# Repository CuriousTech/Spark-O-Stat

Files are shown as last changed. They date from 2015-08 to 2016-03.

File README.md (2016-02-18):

## Spark-O-Stat
SparkCore based WiFi thermostat project

Note: As of 2/18/2016 the SparkCore code is depreciated.  The Photon is now in use, and all changes will be made there.  A new large font has been added since there's more room, and data is published instead of read.  The HTML page and .js scripts will not work with the old code.

This is my first GitHib project, and the idea is simple.  It's opensource and flexible with a color LCD touchscreen, rotary encoder and speaker to allow room for creative software.  The initial concept will be to control for efficiency by scaling the indoor temperature to outdoor instead of drastic bumps using schedules, and adjustments using predictive code based on experiment and observation.  But all that can be removed and replaced with schedules if desired.

UI

A periodic screenshot of data collection: This is sometime in the summer.  The orange temp is in another room.  Unfortunately the thermostat gets the most sun in the house, so it's the most erratic.   I've noticed the AC doesn't run at the low and high points of the day as it used to.  That was unexpected.  And the electric bill was down about 30% most of this year.  

graph

This is the older desktop control running on PngMagic  

control

More info at http://www.curioustech.net/curiousprojects.html

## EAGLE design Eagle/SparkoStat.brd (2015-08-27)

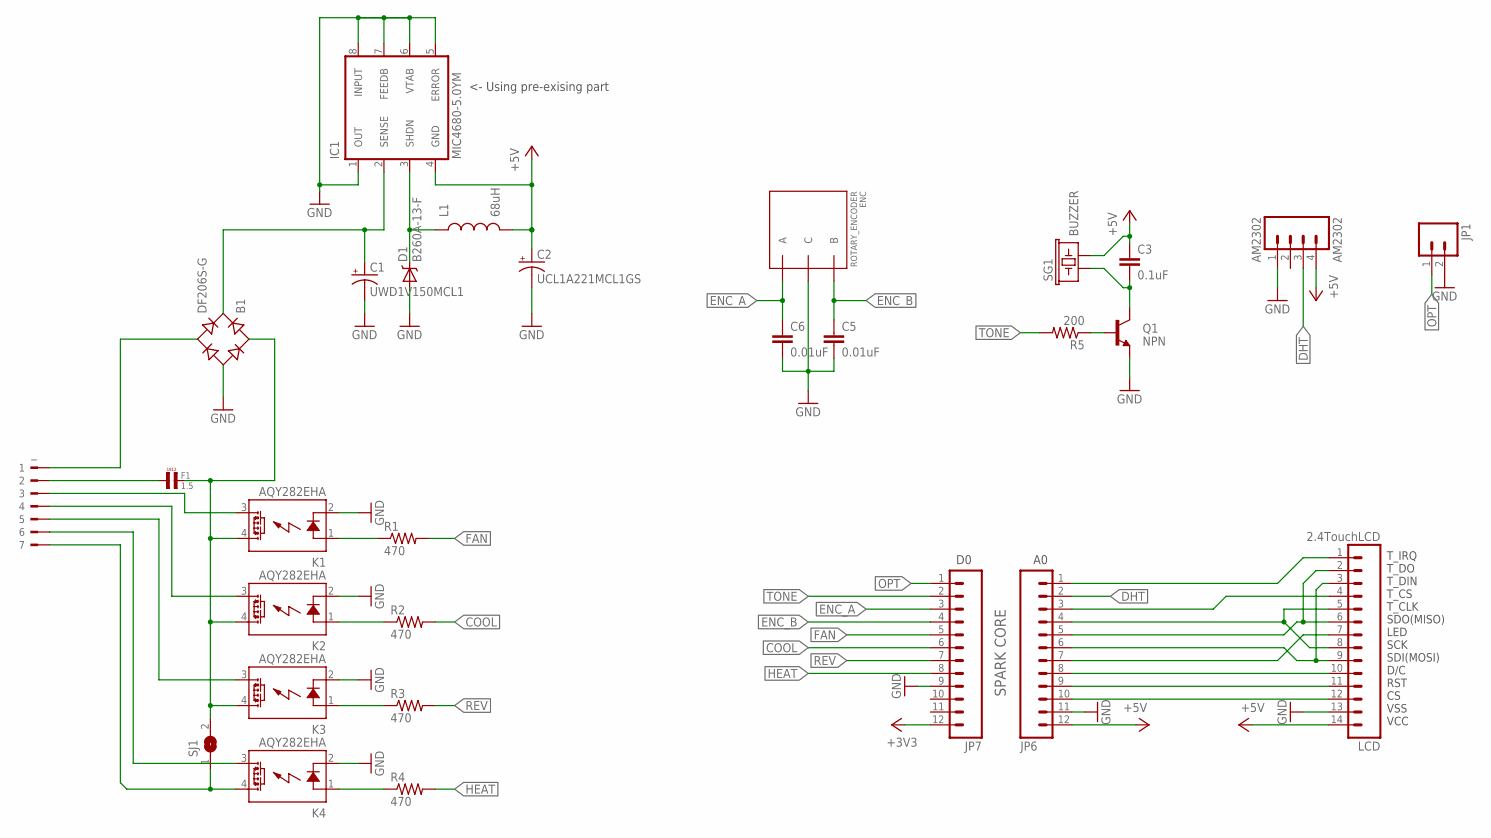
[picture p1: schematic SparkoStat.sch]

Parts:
AM2302: AM2302; 1X04
B1: DF206S-G; DFS
C1: UWD1V150MCL1; PANASONIC_C
C2: UCL1A221MCL1GS; PANASONIC_D
C3: 0.1uF; 0805
C5, C6: 0.01uF; 0805
D1: B260A-13-F; SMA-DIODE
ENC: ROTARY_ENCODER; ROTORY_ENC
F1: 1.5; L4,8
IC1: MIC4680-5.0YM; SO-08
JP1: M02PTH; 1X02
JP6, JP7: M12LOCK; 1X12_LOCK
K1, K2, K3, K4: AQY282EHA; SOP04
L1: 68uH; DR1030
LCD: 2.4TouchLCD; 1X14_LOCK
Q1: NPN; SOT23
R1, R2, R3, R4: 470; 0805
R5: 200; 0805
SG1: BUZZER; BUZZER-12MM-NS
SJ1: SJ
_: 180-7

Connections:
+3V3: JP7.12
+5V: AM2302.4, C2.+, C3.1, IC1.4 (GND), JP6.12, L1.2, LCD.14, SG1.- (2)
COOL: JP7.6, R2.2
DHT: AM2302.3, JP6.2
ENC_A: C6.1, ENC.A, JP7.3
ENC_B: C5.1, ENC.B, JP7.4
FAN: JP7.5, R1.2
GND: AM2302.1, B1.-, C1.-, C2.-, C5.2, C6.2, D1.A, ENC.C, IC1.1 (OUT), IC1.5 (ERROR), IC1.6 (VTAB), IC1.7 (FEEDB), IC1.8 (INPUT), JP1.2, JP6.11, JP7.9, K1.2 (K), K2.2 (K), K3.2 (K), K4.2 (K), LCD.13, Q1.2 (E)
HEAT: JP7.8, R4.2
unnamed: JP6.1, LCD.1
unnamed: D1.C, IC1.3 (SHDN), L1.1
unnamed: K4.3 (DS2), _.6
unnamed: K1.1 (A), R1.1
unnamed: K2.1 (A), R2.1
unnamed: B1.AC1, F1.P$2 (2), K1.4 (DS1), K2.4 (DS1), K3.4 (DS1), SJ1.2
unnamed: K3.1 (A), R3.1
unnamed: K4.1 (A), R4.1
unnamed: K2.3 (DS2), _.4
unnamed: K1.3 (DS2), _.3
unnamed: B1.AC2, _.1
unnamed: JP6.6, LCD.3, LCD.9
unnamed: JP6.5, LCD.2, LCD.6
unnamed: B1.+, C1.+, IC1.2 (SENSE)
unnamed: JP6.9, LCD.11
unnamed: JP6.10, LCD.12
unnamed: JP6.8, LCD.10
unnamed: JP6.4, LCD.5, LCD.8
unnamed: K3.3 (DS2), _.5
unnamed: JP6.7, LCD.7
unnamed: F1.P$1 (1), _.2
unnamed: C3.2, Q1.3 (C), SG1.+ (1)
unnamed: JP6.3, LCD.4
unnamed: K4.4 (DS1), SJ1.1, _.7
unnamed: Q1.1 (B), R5.1
OPT: JP1.1, JP7.1
REV: JP7.7, R3.2
TONE: JP7.2, R5.2

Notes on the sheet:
SPARK CORE
T_IRQ T_DO T_DIN T_CS T_CLK SDO(MISO) LED SCK SDI(MOSI) D/C RST CS VSS VCC
<- Using pre-exising part

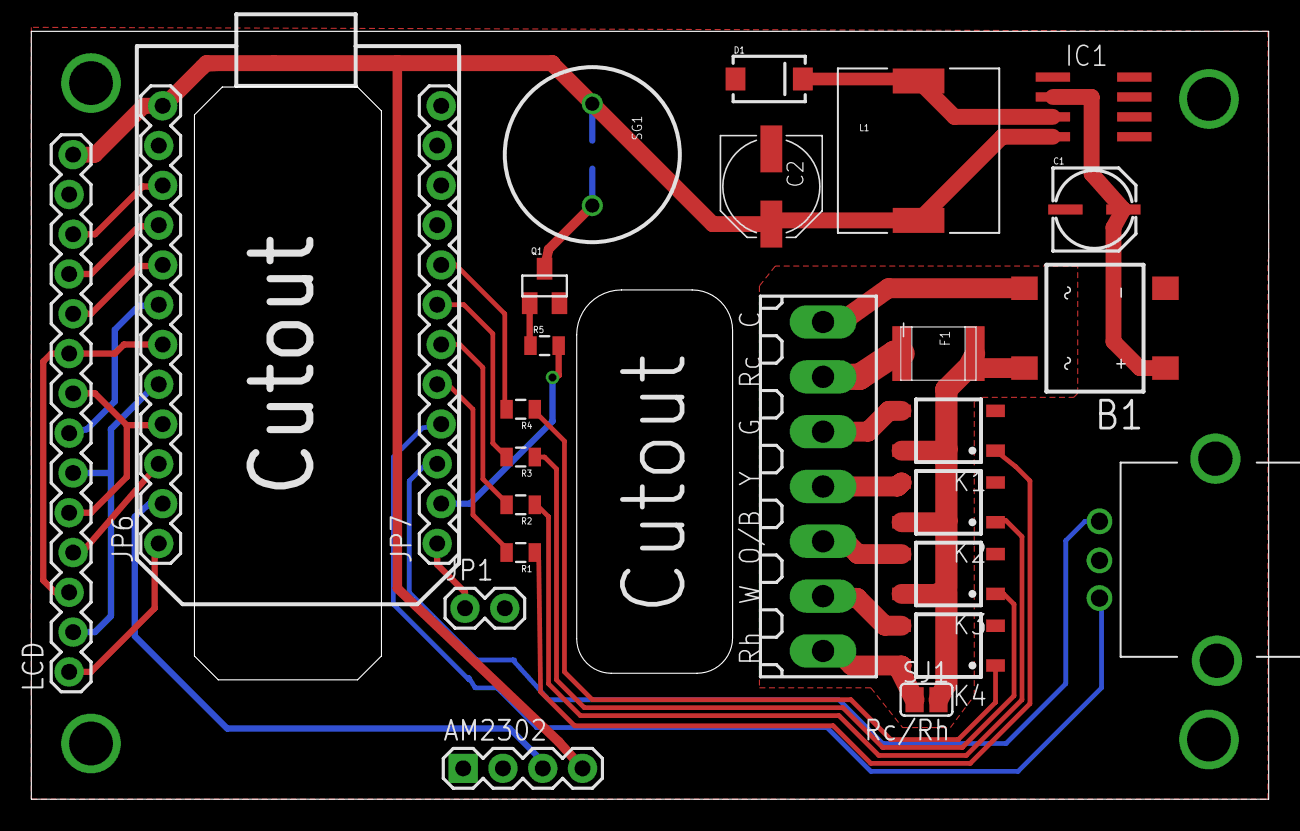
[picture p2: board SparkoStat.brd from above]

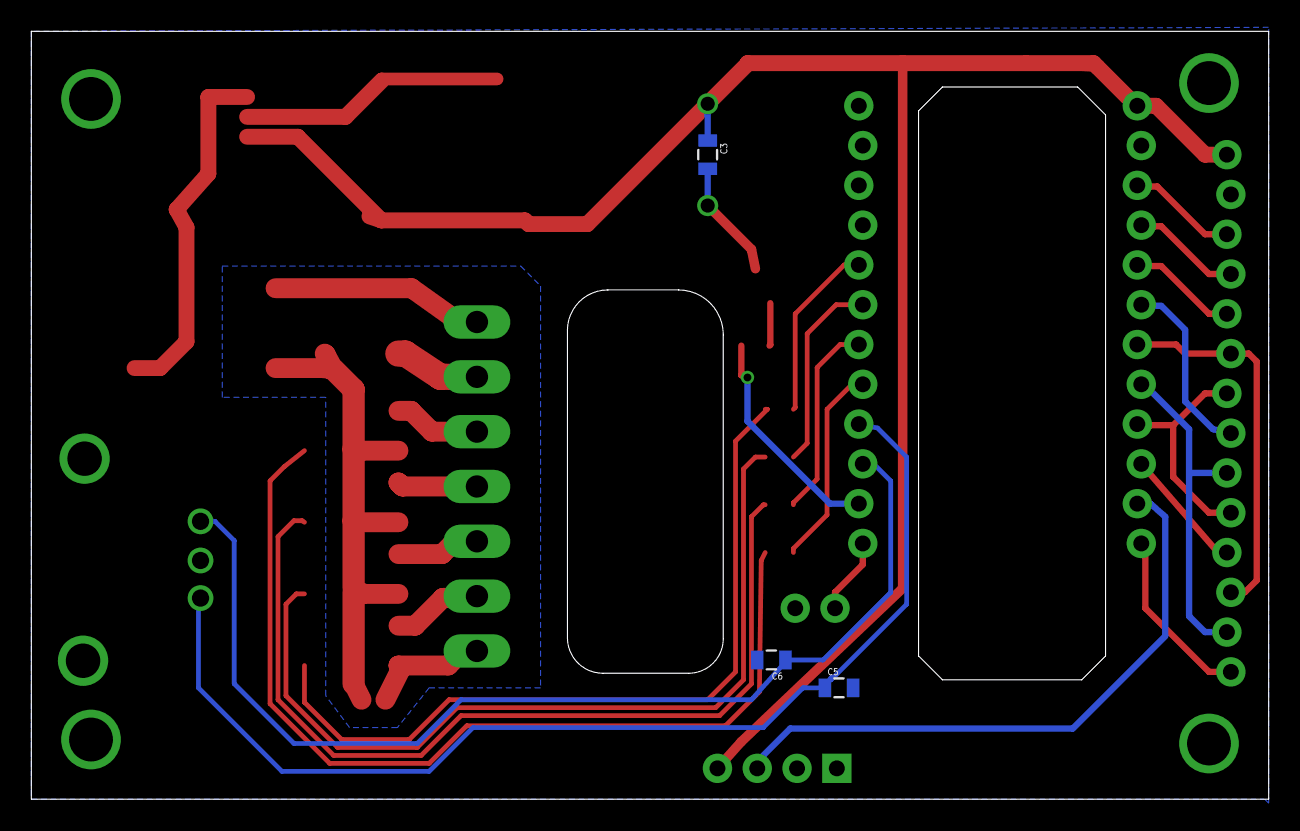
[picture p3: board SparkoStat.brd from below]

Board: 2 copper layers, 79.0 x 49.0 mm, 29 parts (3 on the bottom side), 36 nets.

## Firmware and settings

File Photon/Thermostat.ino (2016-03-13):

//
#include "application.h"

// This #include statement was automatically added by the Particle IDE.
#include "UTouch.h"

// This #include statement was automatically added by the Particle IDE.
#include "PietteTech_DHT/PietteTech_DHT.h"

#include "fonts.h"
// This #include statement was automatically added by the Particle IDE.
#include "Adafruit_ILI9341.h"

// This #include statement was automatically added by the Particle IDE.
#include "Adafruit_mfGFX.h"

#include "HVAC.h"
#include "Encoder.h"
#include "XMLReader.h"

SYSTEM_MODE(SEMI_AUTOMATIC);
SYSTEM_THREAD(ENABLED);

#define FONT_SPACE	6
#define FONT_Y		8
#define CYAN		0xfe00
#define BRIGHT_RED	0xc03f
#define GRAY1		0x8410
#define GRAY2		0x4208

//#define T_CAL     // switch to touchscreen calibration mode (draws hits and 4 temp buttons are calibration values adjusted by thumbwheel)

uint8_t wifi_retry_count = 0;

Forecast m_fcData[20];

//#define T_CAL     // switch to touchscreen calibration mode (draws hits and 4 temp buttons are calibration values adjusted by thumbwheel)

#define ONE_DAY_MILLIS (24 * 60 * 60 * 1000)

unsigned long lastSync;

int8_t  tz = -5;         // timezone and DST
char    ZipCode[] = "41042";

#define DHT_TEMP_ADJUST	(-3.0)	// Adjust indoor temp by degrees
#define DHT_RH_ADJUST    (3.0)	// Adjust indoor Rh by %
#define DHT_PERIOD  (10 * 1000)  // 10 seconds

//--
uint16_t blankSecs = 120;
int8_t  brightness = 100; // in %
int8_t  dimLevel = 0;    // dim level.  0 = off
unsigned long lBacklightTimer;
bool bScreenOn = true;

void drawButton(int8_t btn, bool bDown, bool bFast);
void screenOn(void);

Adafruit_ILI9341 tft = Adafruit_ILI9341(TX, WKP, RX);

UTouch touch(A2, A0);

HVAC hvac = HVAC();

char buffer[260]; // buffer for xml when in use

//-----
void Encoder_callback();

Encoder rot(D2, D3, Encoder_callback);

void Encoder_callback()
{
    rot.isr();
}

//-----
// declaration for DHT22 handler
void dht_wrapper(); // must be declared before the lib initialization

unsigned long lUpdateDHT;
bool bDHT;
// DHT instantiate
PietteTech_DHT DHT(A1, DHT22, dht_wrapper);

void dht_wrapper()
{
    DHT.isrCallback();
}

//-----

static const char _days_short[8][4] = {"", "Sun","Mon","Tue","Wed","Thu","Fri","Sat"};

void displayTime()
{
	char szTime[16];
	static char lastMin = -1;
	static char lastDay = -1;

	sprintf(szTime, "%2d:%02d:%02d %cM", Time.hourFormat12(), Time.minute(), Time.second(), Time.isAM() ? 'A':'P');
	tft.setTextColor(ILI9341_WHITE, ILI9341_BLACK);

	if(szTime[0] == '0') szTime[0] = ' ';

	if(Time.weekday() != lastDay)   // Draw weekday
	{
		tft.setCursor(20, 0);
		tft.drawPropString(_days_short[Time.weekday()], true);
		lastDay = Time.weekday();
	}
    
	if(lastMin == Time.minute()) // draw just seconds
	{
		int x = 75;
		if(szTime[0] != ' ') x += 8; // 0 is 12 pixels
		szTime[8] = 0;     // cut to seconds
		tft.setCursor( x + (3*13) + (2*5), 0);
		tft.drawPropString(szTime + 6, true);
		return;
	}

	lastMin = Time.minute(); // draw full 12H time
	tft.setCursor(70, 0);
	tft.drawPropString(szTime, true); // Time.format("%a %I:%M:%S%p"));
}

XML_tag_t tags[] =
{
	{"time-layout", "time-coordinate", "local", 19},
	{"temperature", "type", "hourly", 19},
	{NULL}
};

unsigned long lUpdateFcst;
unsigned long lUpdateOutTemp;
unsigned long FcstInterval;
bool bReading;
bool bUpdateDST;

void xml_callback(int8_t item, int8_t idx, char *p)
{
	int8_t newtz;
	int8_t h;
	int8_t d;
	static int8_t hO;
	static int8_t lastd;

	switch(item)
	{
		case 0:                             // valid time
			if(!idx)                        // first item isn't really data.  Use for past data
			{
				hO = 0;                     // reset hour offset
				lastd = Time.day();
				break;
			}
			d = atoi(p + 8);                // 2014-mm-ddThh:00:00-tz:00
			h = atoi(p + 11);
			if(d != lastd) hO += 24;        // change to hours offset
			lastd = d;
			hvac.m_fcData[idx-1].h = h + hO;

			newtz = atoi(p + 20);
			if(p[19] == '-')
				newtz = -newtz;

			if(idx < 3 && newtz != tz)
			{
				tz = newtz;
				if(idx == 1)
				{
					Time.zone(tz);      // needs change now
				}
				else
				{
					bUpdateDST = true;  // change it at 2AM
				}
			}
			break;
		case 1:                             // temperature
			if(!idx)                        // 1st value is not temp
				break;
			hvac.m_fcData[idx-1].t = atoi(p);
			break;
	}
}

XMLReader xml(buffer, 257, xml_callback);

// Setup:  NDFD Data For Single Point, zipcode, hourly temp only  (for rh add &rh=rh, for alerts add &wwa=wwa, etc.)
//  http://graphical.weather.gov/xml/sample_products/browser_interface/ndfdXML.htm
//  Other options would be to request different data at different times to split up data that's too large for one time
void GetForecast()
{
	lUpdateFcst = millis();
	
//	Serial.print("Updating forecast at ");
//	Serial.println(Time.timeStr());
	
	char *p_cstr_array[] =
	{
		"/xml/sample_products/browser_interface/ndfdXMLclient.php?zipCodeList=",
		ZipCode,
		"&Unit=e&temp=temp&Submit=Submit",
		NULL
	};

	bReading = xml.begin("graphical.weather.gov", p_cstr_array);
	if(!bReading)
	{
		Particle.publish("status", "forecast failed");
		Serial.println("Forecast failed");
	}
}

// get value at current minute between hours
int tween(int8_t t1, int8_t t2, int m, int8_t h)
{
	if(h == 0) h = 1; // div by zero check
	double t = (double)(t2 - t1) * (m * 100 / (60 * h)) / 100;
	return (int)((t + t1) * 10);
}

// This is where the "current" outdoor temperature is calculated
// When starting up, it may be up to 2 hours ahead
void displayOutTemp()
{
    lUpdateOutTemp = millis();

    int8_t hd = Time.hour() - hvac.m_fcData[0].h;       // hours past 1st value
    int16_t outTemp;

    if(hd < 0)                                          // 1st value is top of next hour
    {
//        Serial.println("future");
        outTemp = hvac.m_fcData[0].t * 10;              // just use it
    }
    else
    {
        int m = Time.minute();              // offset = hours past + minutes of hour

        if(hd) m += (hd * 60);              // add hours ahead (up to 2)

        outTemp = tween(hvac.m_fcData[0].t, hvac.m_fcData[1].t, m, hvac.m_fcData[1].h - hvac.m_fcData[0].h);
    }

    hvac.updateOutdoorTemp(outTemp);

    drawButton(5, false, true);
}
#define Fc_Left     24
#define Fc_Top      26
#define Fc_Right    200
#define Fc_Bottom   77

void drawForecast()
{
	int8_t min = 126;
	int8_t max = -50;
	int8_t i;

	if(hvac.m_fcData[0].h == -1)          // no first run
		return;
		
	int8_t hrs = ( ((hvac.m_fcData[0].h - Time.hour()) + 1) % 3 ) + 1;   // Set interval to 2, 5, 8, 11..
	int8_t mins = (60 - Time.minute() + 54) % 60;   // mins to :54, retry will be :59

	if(mins > 10 && hrs > 2) hrs--;     // wrong

	FcstInterval = ((hrs * 60) + mins) * 60;
    // Get min/max
	for(i = 0; i < 18; i++)
	{
		int8_t t = hvac.m_fcData[i].t;
		if(min > t) min = t;
		if(max < t) max = t;
    }

	if(min == max) max++;   // div by 0 check
	
	hvac.updatePeaks(min, max);

	int16_t y = Fc_Top;
	int16_t incy = (Fc_Bottom - Fc_Top) / 3;
	int16_t dec = (max - min)/3;
	int16_t t = max;
	int16_t x;

	tft.setTextSize(1);
	tft.setTextColor( ILI9341_YELLOW, ILI9341_BLACK );

	tft.fillRect(0, Fc_Top, Fc_Right, Fc_Bottom-Fc_Top+FONT_Y+1, ILI9341_BLACK);

    // temp scale and h-lines
	for(i = 0; i <= 3; i++)
	{
		x = Fc_Left - FONT_SPACE - 1;           // to left
		if( t < 0) x -= FONT_SPACE;             // neg
		if( t < -9 || t > 9) x -= FONT_SPACE;   // 2 digit
		if( t > 99) x -= FONT_SPACE;            // another digit (probably not -100)

        tft.setCursor(x, y-(FONT_Y>>1));
        tft.print(t);
		tft.drawFastHLine(Fc_Left, y, Fc_Right-Fc_Left, GRAY1);
		y += incy;
		t -= dec;
	}

	tft.drawFastVLine(Fc_Left, Fc_Top, Fc_Bottom - Fc_Top, GRAY1); // left side
	tft.drawFastVLine(Fc_Right, Fc_Top, Fc_Bottom - Fc_Top, GRAY1); // right side

	int8_t day = Time.weekday()-1;              // current day
	int8_t h0 = Time.hour();                    // zeroeth hour
	int8_t pts = hvac.m_fcData[17].h - h0;
	int8_t h;
	int16_t day_x = 0;

	if(pts <= 0) return;                     // error

	for(i = 0, h = h0; i < pts; i++, h++)    // v-lines
	{
		x = Fc_Left + (Fc_Right-Fc_Left) * i / pts;
		if( (h % 24) == 0) // midnight
		{
			tft.drawFastVLine(x, Fc_Top, Fc_Bottom - Fc_Top, GRAY1);
			if(x - 49 > Fc_Left) // fix 1st day too far left
			{
				tft.setCursor(day_x = x - 49, Fc_Bottom + 2);
				tft.print(_days_short[day]);
			}
			if(++day >6) day = 0;
		}
		if( (h % 24) == 12) // noon
		{
			tft.drawFastVLine(x, Fc_Top, Fc_Bottom - Fc_Top, GRAY2);
		}
	}

	day_x += 84;
	if(day_x < Fc_Right - (FONT_SPACE*3) )
	{
		tft.setCursor(day_x, Fc_Bottom + 2);       // draw last day
		tft.print(_days_short[day]);
	}
	int16_t y2 = Fc_Bottom - 1 - (hvac.m_fcData[0].t - min) * (Fc_Bottom-Fc_Top-2) / (max-min);
	int16_t x2 = Fc_Left;

	for(i = 0; i < 18; i++)
	{
		int y1 = Fc_Bottom - 1 - (hvac.m_fcData[i].t - min) * (Fc_Bottom-Fc_Top-2) / (max-min);
		int x1 = Fc_Left + (hvac.m_fcData[i].h - h0) * (Fc_Right-Fc_Left) / pts;
		tft.drawLine(x2, y2, x1, y1, ILI9341_RED);
		x2 = x1;
		y2 = y1;
	}

	displayOutTemp();
}

//----------------
typedef struct
{
	const uint8_t x, y, w, h;
} Button;


Button buttons[] =
{// Left, top, wid, hi
    {224, 137,  90, 25},    // 0 cool temp high (do not change positon: buttons 0-3 refrenced elsewhere)
    {224, 162,  90, 25},    // 1 cool temp low
    {224, 187,  90, 25},    // 2 heat temp high
    {224, 212,  90, 25},    // 3 heat temp low

    {224,  108,  90, 25},    // 4 target temp

    {240,  22,  80, 24},    // 5 out temp - change button # in displayOutTemp
    {240,  46,  80, 24},    // 6 in temp  - change button #s in updateDHT
    {240,  70,  80, 24},    // 7 in rh    - "  "

    {  4,  91,  72, 34},    // 8 fan  (do not change positon: fan/mode reference in hvac.setMode)
    {  4, 128,  72, 34},    // 9 mode
    {  4, 165,  72, 34},    // 10 gas/elec

    {  4, 202, 216, 34},    // 11 Notifications (filter)  18 char max

    { 0, 0, 0, 0}
};

int8_t  adjustMode;
int8_t  dispNote = -1;

const char  *pszHvacFan[] = {"Auto", " On "};
const char  *pszHvacMode[] = {"Off ", "Cool", "Heat", "Auto"};
const char  *pszHeatMode[] = {" HP ", " NG ", "Auto"};

// convert n*10 to XXX.X with neg
void cvtNum(char *p, int num)
{
    if( num < 0)
    {
        p[0] = '-';
        num = -num;
    }
    else
    {
        p[0] = ' ';
    }
    p[4] = '0' + (num % 10);
    num /= 10;
    p[3] = '.';
    p[2] = '0' + (num % 10);
    num /= 10;
    p[1] = num ? ('0' + (num % 10)) : p[0]; // copy space or - if 2.1 digits
    num /= 10;
    if(p[1] == '-') p[0] = ' '; // remove --1.1 if -1.1
    if(num) p[1] = '0' + num;   // 3.1 will only be +
    p[5] = 0;
}

#ifdef T_CAL
// convert n to XXXXX with neg
void cvtNumD(char *p, int num)
{
    if( num < 0)
    {
        p[0] = '-';
        num = -num;
    }
    else
    {
        p[0] = ' ';
    }
    p[4] = '0' + (num % 10);
    num /= 10;
    p[3] = '0' + (num % 10);
    num /= 10;
    p[2] = '0' + (num % 10);
    num /= 10;
    p[1] = num ? ('0' + (num % 10)) : p[0];
    num /= 10;
    if(num) p[1] = '0' + num;
    p[5] = 0;
}
#endif

int16_t vals[5]; // the displayed value of a temp button

void drawButton(int8_t btn, bool bDown, bool bFast) // draw a button with pressed state and updated text
{
    uint16_t fg = ILI9341_WHITE;                // default text color
    uint16_t bg = bDown ? ILI9341_RED:ILI9341_BLACK;    // default bg color
    bool    bDeg = false;

    char szText[8] = "";
    char *pszText = szText;

    if(btn < 0)
        return;

    int16_t v;
    int i;
    static bool bBlink = false;
    int8_t m = (hvac.getMode() == Mode_Auto) ? hvac.getAutoMode() : hvac.getMode();

    switch(btn)
    {
        case 0: // cool temp hi
        case 1: // cool temp low
        case 2: // heat temp hi
        case 3: // heat temp low
#ifdef T_CAL
            v = touch.getCal(btn);
            if(bFast && v == vals[btn])
                return;
            cvtNumD(szText, vals[btn] = v);
            bg = (adjustMode == btn) ? GRAY1 : ILI9341_BLACK;
#else       //
            v = hvac.getSetTemp( (btn < 2 ) ? Mode_Cool : Mode_Heat, (btn^1) & 1 );
            if(bFast && v == vals[btn])
                return;
            cvtNum(szText, vals[btn] = v );
            fg = (btn < 2) ? ILI9341_BLUE:ILI9341_RED;
            bg = (adjustMode == btn) ? GRAY1 : ILI9341_BLACK;
            bDeg = true;
#endif
            break;
        case 4:     // target temp
            v = hvac.m_targetTemp;
            if(bFast && v == vals[btn])
                return;
            cvtNum(szText, vals[btn] = v );
            fg = ILI9341_GREEN;
            switch(m)
            {
                case Mode_Cool:
                    fg = ILI9341_BLUE;
                    break;
                case Mode_Heat:
                    fg = ILI9341_RED;
                    break;
            }
            bBlink = !bBlink;
            bg = hvac.getState() ? (bBlink ? GRAY1:fg) : ILI9341_BLACK;
            bDeg = true;
            break;

        case 5: // out temp
            cvtNum(szText, 752 );
            bDeg = true;
            break;
        case 6: // in temp
            cvtNum(szText, (int)((DHT.getFahrenheit() + DHT_TEMP_ADJUST) * 10) );         // display adjusted indoor temp
            bDeg = true;
            break;
        case 7: // in rh
            cvtNum(szText, (int)((DHT.getHumidity() + DHT_RH_ADJUST) * 10) );
            szText[5] = '%';
            szText[6] = 0;
            break;
        case 8: // fan
            pszText = (char *)pszHvacFan[ hvac.getFan() ];
            bg = bDown ? ILI9341_RED:ILI9341_BLUE;
            break;
        case 9: // mode
            pszText = (char *)pszHvacMode[ hvac.getSetMode() ];
            bg = bDown ? ILI9341_RED:ILI9341_BLUE;
            break;
        case 10: // heat mode
            pszText = (char *)pszHeatMode[ hvac.getHeatMode() ];
            bg = bDown ? ILI9341_RED:ILI9341_BLUE;
            break;
        case 11: // Notifications
            pszText = "               ";
            for(i = 0; i < 8; i++)
            {
                if(hvac.m_pszNote[i])   // find one
                {
                    pszText = (char *)hvac.m_pszNote[i];
                    dispNote = i;
                    tone(D1, 3000, 200);    // make noise
                    delay(200);
                    tone(D1, 3200, 200);
                    bg = ILI9341_BLUE;
                    break;
                }
            }
            break;
    }

    tft.fillRect(buttons[btn].x, buttons[btn].y, buttons[btn].w, buttons[btn].h, ILI9341_BLACK);

    int16_t l = (buttons[btn].w>>1) - (tft.propStringLength(pszText)>>1);
    int16_t t = (buttons[btn].h>>1) - FONT_Y - 1;

    tft.setCursor(buttons[btn].x + l, buttons[btn].y + t);
    tft.setTextColor(fg, ILI9341_BLACK);
    int x = tft.drawPropString((char*)pszText, false);

    if(bDeg)
        tft.drawCircle(x + 1, buttons[btn].y + t + 3, 2, fg);     // add a degree symbol
    tft.drawRoundRect(buttons[btn].x, buttons[btn].y, buttons[btn].w, buttons[btn].h, 3, bg); // draw rect after text
}

void refreshTemps(void)
{
    for(int i = 0; i < 4; i++)
        drawButton(i, false, true);

    drawButton(11, false, true);
}

void HandleTouch(bool bDown)
{
	static int8_t lastButton = -1;
	static int16_t lastX = -1, lastY = -1;
	static bool bPress = false;
	
	lBacklightTimer = millis();     // reset screensaver
	
	if(!bScreenOn)
	{
		Backlight(brightness);
		bScreenOn = true;
		lastButton = -1;
		return;     // block first press if screen was off
	}
	
	if( !bDown )      // button release
	{
		drawButton(lastButton, false, false);
		bPress = false;
		return;
	}
	
	touch.read();
	int16_t x = touch.getX();
	int16_t y = touch.getY();
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
void loop()
{
    static int8_t lastSec;
    static int8_t lastHour;
    static int8_t lastMode;
    static bool bDown = false;
    static uint8_t nState = 0;
    static bool bFan = false;
    static char szPub[128];

    if( touch.pressed() )
    {
        bDown = true;
        HandleTouch(true);
    }
    else
    {
        if(bDown)
            HandleTouch(false);     // release
        bDown = false;
    }
    
    while( EncoderCheck() );

	if(Time.second() != lastSec)   // things to do every second
	{
		lastSec = Time.second();

        if(lastSec & 1)
        {
            if(wifi_retry_count < 10)
            {
                if(!WiFi.ready())
                {
                    hvac.disable();
                    WiFi.connect();
                    wifi_retry_count++;
                }
                else if(!Particle.connected())
                {
                    hvac.disable();
                    Particle.connect();
                    wifi_retry_count++;
                }
                else // all good?
                {
                    hvac.enable();
                }
            }
            else
            {
                hvac.disable();
                WiFi.off();
                wifi_retry_count = 0;
                WiFi.on();
            }
        }

        if(millis() - lastSync >= ONE_DAY_MILLIS)
        {
            Particle.syncTime();       // time sync every 24 hours
            lastSync = millis();
        }

        if(lastHour != Time.hour())     // things to do on the hour
        {
            lastHour = Time.hour();

            if(lastHour == 2 && bUpdateDST) // DST changes at 2AM
            {
                bUpdateDST = false;
                Time.zone(tz);
            }

            if(dispNote >= 0)  // if notification or critical error
            {
                tone(D1, 3000, 200);    // make noise
                delay(200);
                tone(D1, 3200, 200);
            }
            UpdateEE();          // EE updates will go here for now (every hour)
	    }

        displayTime();
        hvac.service();
        drawSignal(150, 90, 40);

        if(hvac.getMode() != lastMode || hvac.getState() != nState || bFan != hvac.getFanRunning())   // erase prev highlight
        {
            lastMode = hvac.getMode();
            drawButton(1, false, false);
            drawButton(2, false, false);
            sprintf(szPub, "{\"Mode\": %u, \"State\": %u, \"Fan\": %u}", lastMode, nState = hvac.getState(), bFan = hvac.getFanRunning());
            Particle.publish("stateChg", szPub);
        }

        drawButton(4, false, false);     // target

//        displayHvacPins();

        if(bDHT)    // this is 1 sec after acquire
        {
            bDHT = false;
            if(DHT.getStatus()  == DHTLIB_OK)
            {
                hvac.updateIndoorTemp( (int)((DHT.getFahrenheit() + DHT_TEMP_ADJUST) * 10), (int)((DHT.getHumidity()+DHT_RH_ADJUST) * 10) );

//                Serial.print("Temp: ");
//                Serial.println( DHT.getFahrenheit() );
                drawButton(6, false, true);     // in temp
                drawButton(7, false, true);     // rh
            }

            lUpdateDHT = millis();
        }
        else if(millis() - lUpdateDHT >= DHT_PERIOD)
        {
		    DHT.acquire();
		    bDHT = true;
        }

        if(bReading)
        {
            bReading = xml.service(tags);
            if(!bReading)
            {
//              Serial.print("XMLReader done: Status = ");
//              Serial.println(xml.getStatus());
                switch(xml.getStatus())
                {
                    case XML_DONE:
                        drawForecast();
                        Particle.publish("status", "forecast success");
                    	hvac.enable();
                        break;
                    case  XML_TIMEOUT:
                    default:
                        hvac.disable();
                        Particle.publish("status", "forecast timeout");
                        hvac.addNotification( "No NDFD Update " );
                        FcstInterval = 5 * 60;    // retry in 5 mins
                        break;
                }
            }
        }

        if(millis() - lUpdateFcst >= (FcstInterval * 1000) )
        {
            GetForecast();
        }

        if(millis() - lUpdateOutTemp >= (5 * 60 * 1000) )        // update every 5 mins
        {
            displayOutTemp();
        }

        if(millis() - lBacklightTimer >= (blankSecs*1000) )     // screen blanker
        {
            Backlight(dimLevel);
            bScreenOn = false;
        }
    }
    delay(50);
}

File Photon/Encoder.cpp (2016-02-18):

#include "application.h"
#include "Encoder.h"
 
Encoder::Encoder(int8_t aPin, int8_t bPin, void (*callback)())
{
    pinMode(aPin, INPUT_PULLUP);
    pinMode(bPin, INPUT_PULLUP);

	m_aPin = aPin;
	m_bPin = bPin;

    m_lastA = digitalRead(aPin);
    attachInterrupt(aPin, callback, FALLING);
}

int Encoder::poll()
{
    int8_t A = digitalRead(m_aPin);

    m_dir = 0;

    if(!A && A != m_lastA)  // simulate falling edge of A
    {
        m_ticks ++;
        m_dir = digitalRead(m_bPin) ? -1 : 1;
    }

    m_lastA = A;
    return m_dir;
}

// get changes
int Encoder::read()
{
    if(m_ticks == 0)
        return 0;
    int n = m_dir * m_ticks;
    m_ticks = 0;
    return n;
}

// isr (falling edge of A)
void Encoder::isr()
{
    m_ticks++;
    m_dir = digitalRead(m_bPin) ? -1 : 1;
}

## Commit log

2015-01-26 Create Encoder.h
    Rotary encoder library header, Encoder class def.
2015-01-26 Create Encoder.cpp
    Simple rotory encoder class. Interrupt or poll.
2015-01-26 Create SparkoStat.sch
    Eagle schematic
    [SparkoStat.sch]
2015-01-26 Create SparkoStat.brd
    Eagle board layout
    [SparkoStat.brd]
2015-01-27 Tabs and error checking added
    [HVAC.cpp]
2015-01-29 Figured out folders!
    [SparkoStat.sch]
2015-04-16 autoMode heatMode fix
2015-05-28 Auto heatmode, particle.io update
2015-05-28 Adding auto heat mode option
2015-07-28 Heatpump solenoid was reversed, sim in ifdef
    [HVAC.cpp]
2015-07-28 Add override button
2015-08-07 Update HVAC.cpp
    Change override to delta
    heatpump switch while running fix
    [HVAC.cpp]
2015-08-12 Swapped target and threshold
    [HVAC.cpp]
2015-08-27 Changed DHT22 to verticle
    [SparkoStat.sch]
2015-09-18 Add publish event for mode, run, fan change
2015-10-08 filter counter now minutes
2015-10-13 Added remote temperature control
2015-10-13 Added cancel to remote temperature control
2015-10-16 Added simulated fan state for furnace override
2015-11-18 Changed filter counter
2015-11-27 Tab bug in github
    [Thermostat.ino]
2015-12-17 Split fan post time for HP/cool
2016-01-16 Sort of radio button style
2016-01-31 Fan was stopping when fanMode = on after cycle

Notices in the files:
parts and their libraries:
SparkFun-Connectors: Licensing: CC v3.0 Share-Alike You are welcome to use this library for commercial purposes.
